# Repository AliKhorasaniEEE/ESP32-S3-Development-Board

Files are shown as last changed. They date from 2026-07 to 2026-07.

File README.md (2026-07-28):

# ESP32-S3 Development Board

A custom ESP32-S3-WROOM-1 development board designed in KiCad.

## Overview

This project is a two-layer ESP32-S3 development board featuring USB Type-C connectivity, USB-to-UART programming, onboard 3.3 V regulation, and access to all ESP32-S3 GPIO pins.

The board was designed as a learning project to gain practical experience in professional PCB design using KiCad.

---

## Features

- ESP32-S3-WROOM-1 module
- USB Type-C connector
- CP2102N USB-to-UART bridge
- AMS1117-3.3 V voltage regulator
- Reset and Boot buttons
- All 40 ESP32-S3 pins exposed
- Two-layer PCB
- Ground plane
- Decoupling capacitors placed according to the reference design

---

## Main Components

| Component | Part Number |
|---|---|
| MCU | ESP32-S3-WROOM-1 |
| USB-UART | CP2102N |
| Voltage Regulator | AMS1117-3.3 |
| USB Connector | USB Type-C 16-Pin |

---

## Software

Designed using:

- KiCad 10.0.4

---

## Repository Structure

Hardware/
KiCad project files

Images/
PCB renders and screenshots

---

## Images

### PCB

PCB

### Schematic

Schematics

### 3D View



---

## Project Status

Current Revision: A

Prototype

**Hardware has not yet been manufactured or electrically validated.**

---

## Future Improvements

- Replace AMS1117 with a low-dropout regulator
- Improve ground stitching
- Optimize routing
- Hardware validation
- Revision B

---
## References

- Espressif ESP32-S3 Hardware Design Guidelines
- Espressif ESP32-S3-WROOM-1 Datasheet
- CP2102N Datasheet
- KiCad Official Libraries

## License

MIT License

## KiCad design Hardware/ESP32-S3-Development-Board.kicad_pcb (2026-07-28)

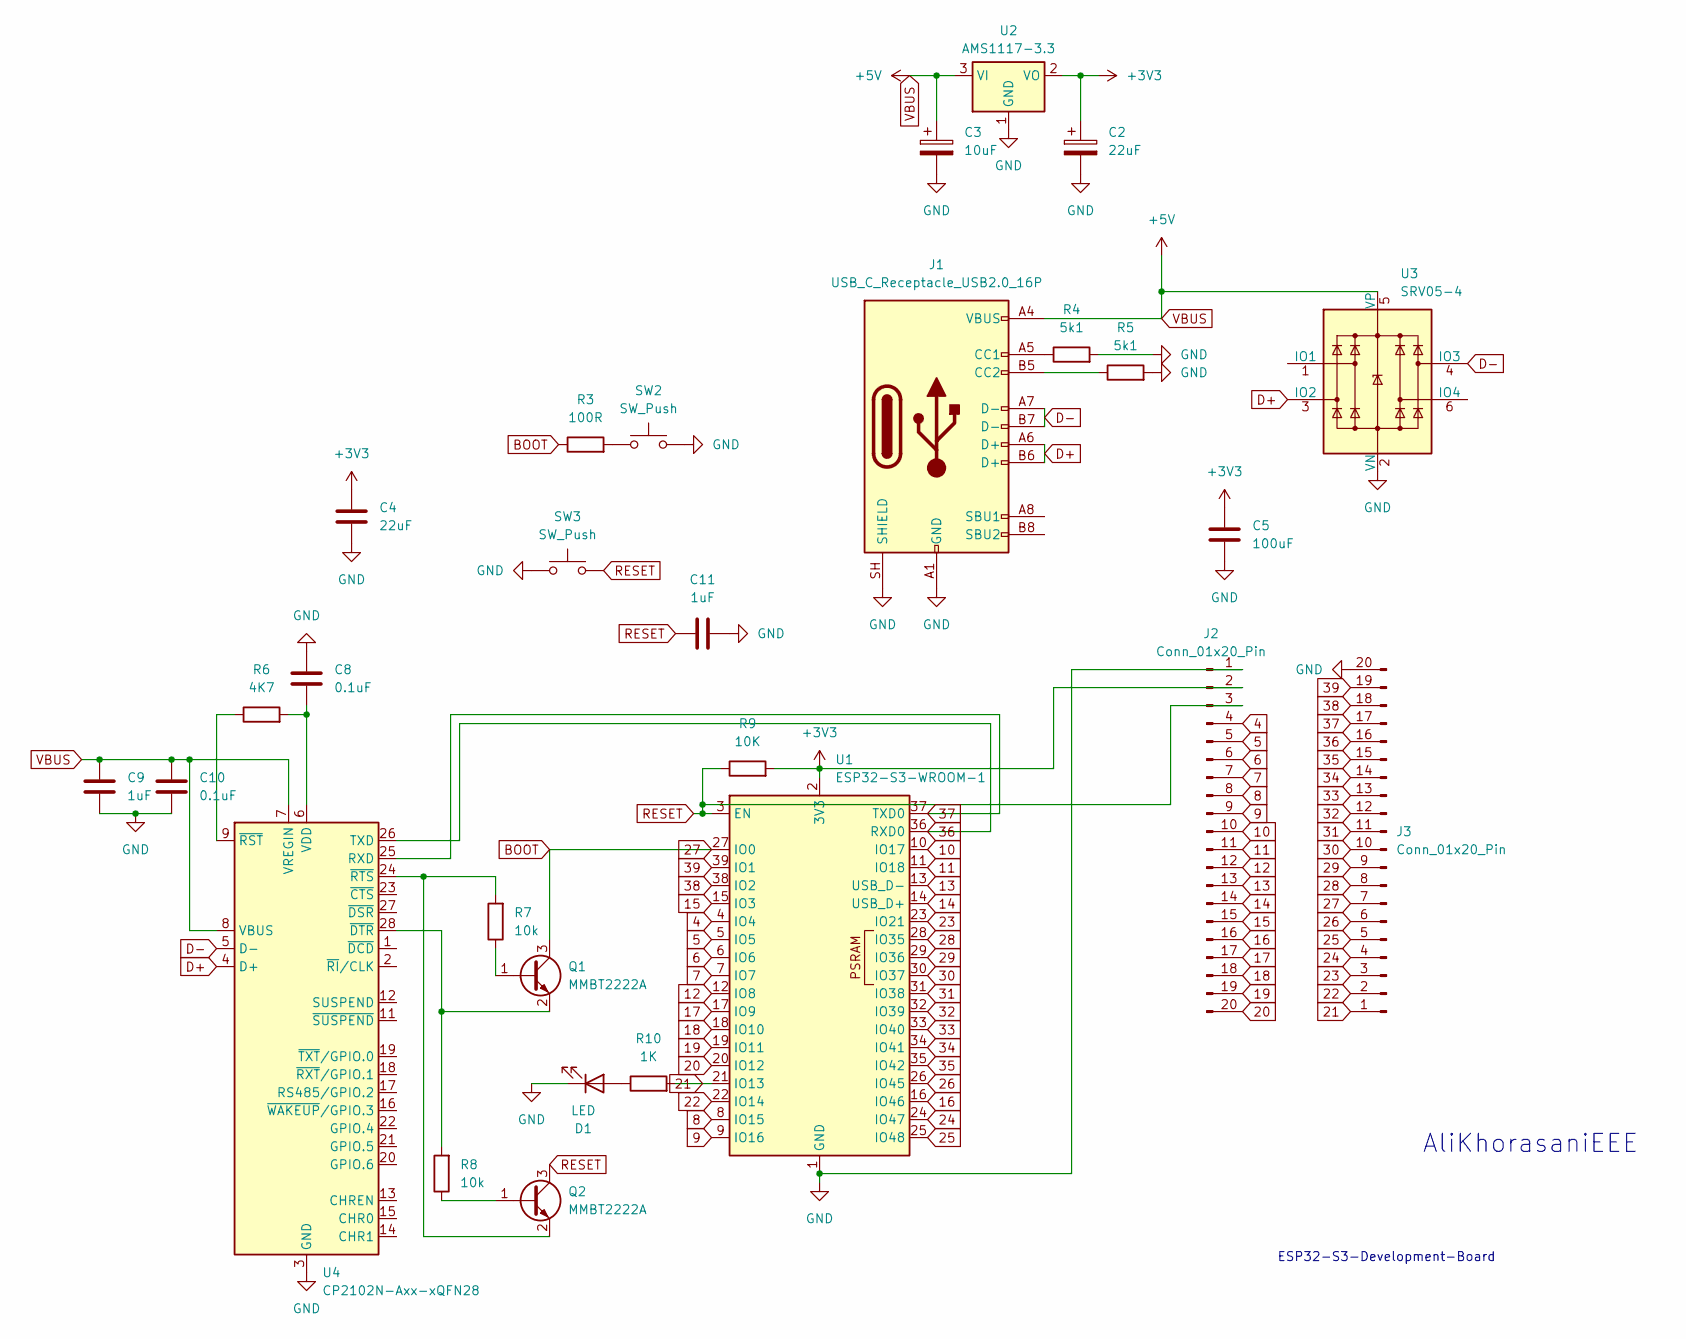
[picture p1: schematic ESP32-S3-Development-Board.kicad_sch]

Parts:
C2, C4: 22uF; C_1206_3216Metric
C3: 10uF; C_1206_3216Metric
C5: 100uF; C_1206_3216Metric
C8, C10: 0.1uF; C_1206_3216Metric
C9, C11: 1uF; C_1206_3216Metric
D1: LED; LED_0603_1608Metric
J1: USB_C_Receptacle_USB2.0_16P; USB_C_Receptacle_GCT_USB4105-xx-A_16P_TopMnt_Horizontal
J2, J3: Conn_01x20_Pin; PinHeader_1x20_P1.00mm_Vertical
Q1, Q2: MMBT2222A; SOT-23
R3: 100R; R_0805_2012Metric
R4, R5: 5k1; R_0805_2012Metric
R6: 4K7; R_0805_2012Metric
R7, R8: 10k; R_0805_2012Metric
R9: 10K; R_0805_2012Metric
R10: 1K; R_0805_2012Metric
SW2, SW3: SW_Push; SW_Push_SPST_NO_Alps_SKRK
U1: ESP32-S3-WROOM-1
U2: AMS1117-3.3; SOT-223-3_TabPin2
U3: SRV05-4; SOT-23-6
U4: CP2102N-Axx-xQFN28; QFN-28-1EP_5x5mm_P0.5mm_EP3.35x3.35mm

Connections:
4: J2.4, U1.4 (IO4)
5: J2.5, U1.5 (IO5)
6: J2.6, U1.6 (IO6)
7: J2.7, U1.7 (IO7)
8: J2.8, U1.8 (IO15)
9: J2.9, U1.9 (IO16)
10: J2.10, U1.10 (IO17)
11: J2.11, U1.11 (IO18)
12: J2.12, U1.12 (IO8)
13: J2.13, U1.13 (USB_D-)
14: J2.14, U1.14 (USB_D+)
15: J2.15, U1.15 (IO3)
16: J2.16, U1.16 (IO46)
17: J2.17, U1.17 (IO9)
18: J2.18, U1.18 (IO10)
19: J2.19, U1.19 (IO11)
20: J2.20, U1.20 (IO12)
21: J3.1, R10.2, U1.21 (IO13)
22: J3.2, U1.22 (IO14)
23: J3.3, U1.23 (IO21)
24: J3.4, U1.24 (IO47)
25: J3.5, U1.25 (IO48)
26: J3.6, U1.26 (IO45)
27: J3.7, Q1.3 (C), R3.1, U1.27 (IO0)
28: J3.8, U1.28 (IO35)
29: J3.9, U1.29 (IO36)
30: J3.10, U1.30 (IO37)
31: J3.11, U1.31 (IO38)
32: J3.12, U1.32 (IO39)
33: J3.13, U1.33 (IO40)
34: J3.14, U1.34 (IO41)
35: J3.15, U1.35 (IO42)
36: J3.16, U1.36 (RXD0), U4.26 (TXD)
37: J3.17, U1.37 (TXD0), U4.25 (RXD)
38: J3.18, U1.38 (IO2)
39: J3.19, U1.39 (IO1)
+3V3: C2.1, C4.1, C5.1, J2.2, R9.2, U1.2 (3V3), U2.2 (VO)
D+: J1.A6 (D+), J1.B6 (D+), U3.3 (IO2), U4.4 (D+)
D-: J1.A7 (D-), J1.B7 (D-), U3.4 (IO3), U4.5 (D-)
GND: C2.2, C3.2, C4.2, C5.2, C8.2, C9.2, C10.1, C11.2, D1.1 (K), J1.A1 (GND), J1.A12 (GND), J1.B1 (GND), J1.B12 (GND), J1.SH (SHIELD), J2.1, J3.20, R4.2, R5.2, SW2.2, SW3.1, U1.1 (GND), U1.40 (GND), U1.41 (GND), U2.1 (GND), U3.2 (VN), U4.3 (GND), U4.29 (GND)
unnamed: D1.2 (A), R10.1
unnamed: J1.A5 (CC1), R4.1
unnamed: J1.B5 (CC2), R5.1
unnamed: Q1.1 (B), R7.1
unnamed: Q1.2 (E), R8.2, U4.28 (~DTR)
unnamed: Q2.1 (B), R8.1
unnamed: Q2.2 (E), R7.2, U4.24 (~RTS)
unnamed: R3.2, SW2.1
unnamed: C8.1, R6.2, U4.6 (VDD)
unnamed: R6.1, U4.9 (~RST)
RESET: C11.1, J2.3, Q2.3 (C), R9.1, SW3.2, U1.3 (EN)
VBUS: C3.1, C9.1, C10.2, J1.A4 (VBUS), J1.A9 (VBUS), J1.B4 (VBUS), J1.B9 (VBUS), U2.3 (VI), U3.5 (VP), U4.7 (VREGIN), U4.8 (VBUS)

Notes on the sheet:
AliKhorasaniEEE
ESP32-S3-Development-Board

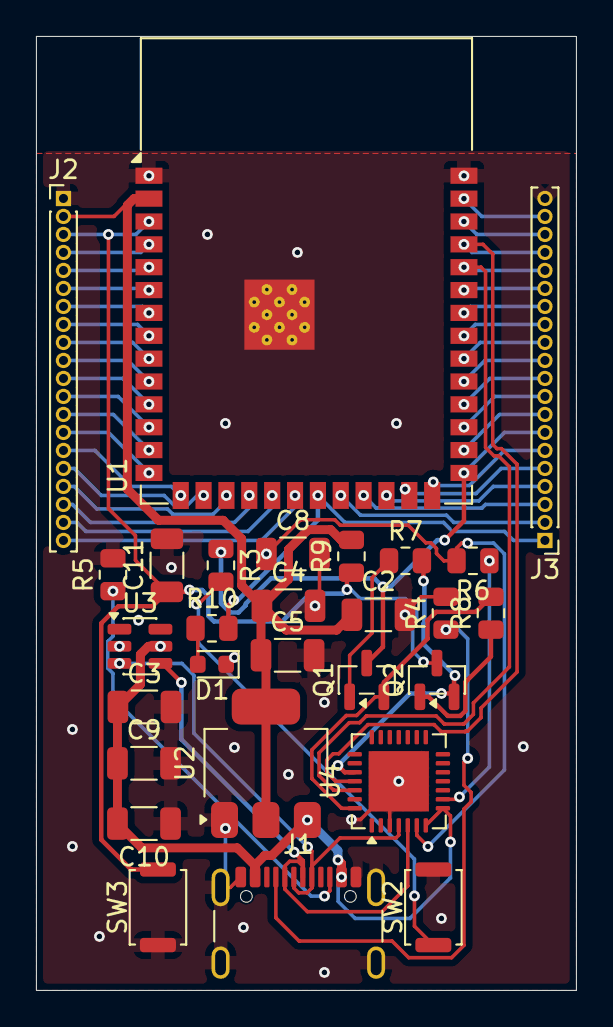
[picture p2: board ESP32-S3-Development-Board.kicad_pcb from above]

Board: 2 copper layers, 30.0 x 53.0 mm, 28 parts (0 on the bottom side), 52 nets.
